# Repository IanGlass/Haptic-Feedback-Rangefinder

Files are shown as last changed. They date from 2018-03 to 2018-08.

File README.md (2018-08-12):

# Haptic-Feedback-Rangefinder

The purpose of this project was to design a hand held rangefinder which uses vibration intensity (haptic feedback) to indicate distance. The sensing range can be cycled between 100, 200 and 400 cm using the push button, where the intensity of vibration indicates the distance from the maximum distance. A switch is also present to switch the device on and off. The device also has charge indication to let the user know it is charging, by way of a couple of vibrations as feedback. The device will not operate when in charge mode. This project uses the HC-SR04 ultrasonic sensor and the EFM32TG microcontroller produced by SiliconLabs.

# Circuit

The Li-ion battery is voltage regulated to a nominal 3.5 V, providing power to the microcontroller. Battery charge is controlled with the MCP73831, which is powered through a 5 V USB source. MOSFETs are not required for normal operation but allows the micro to power up and indicate 'charging' with a few short vibration bursts from the motor (Charge tag leading to PA0 on the micro). The device has a 50 mA average measured current usage. 

<p align="center">
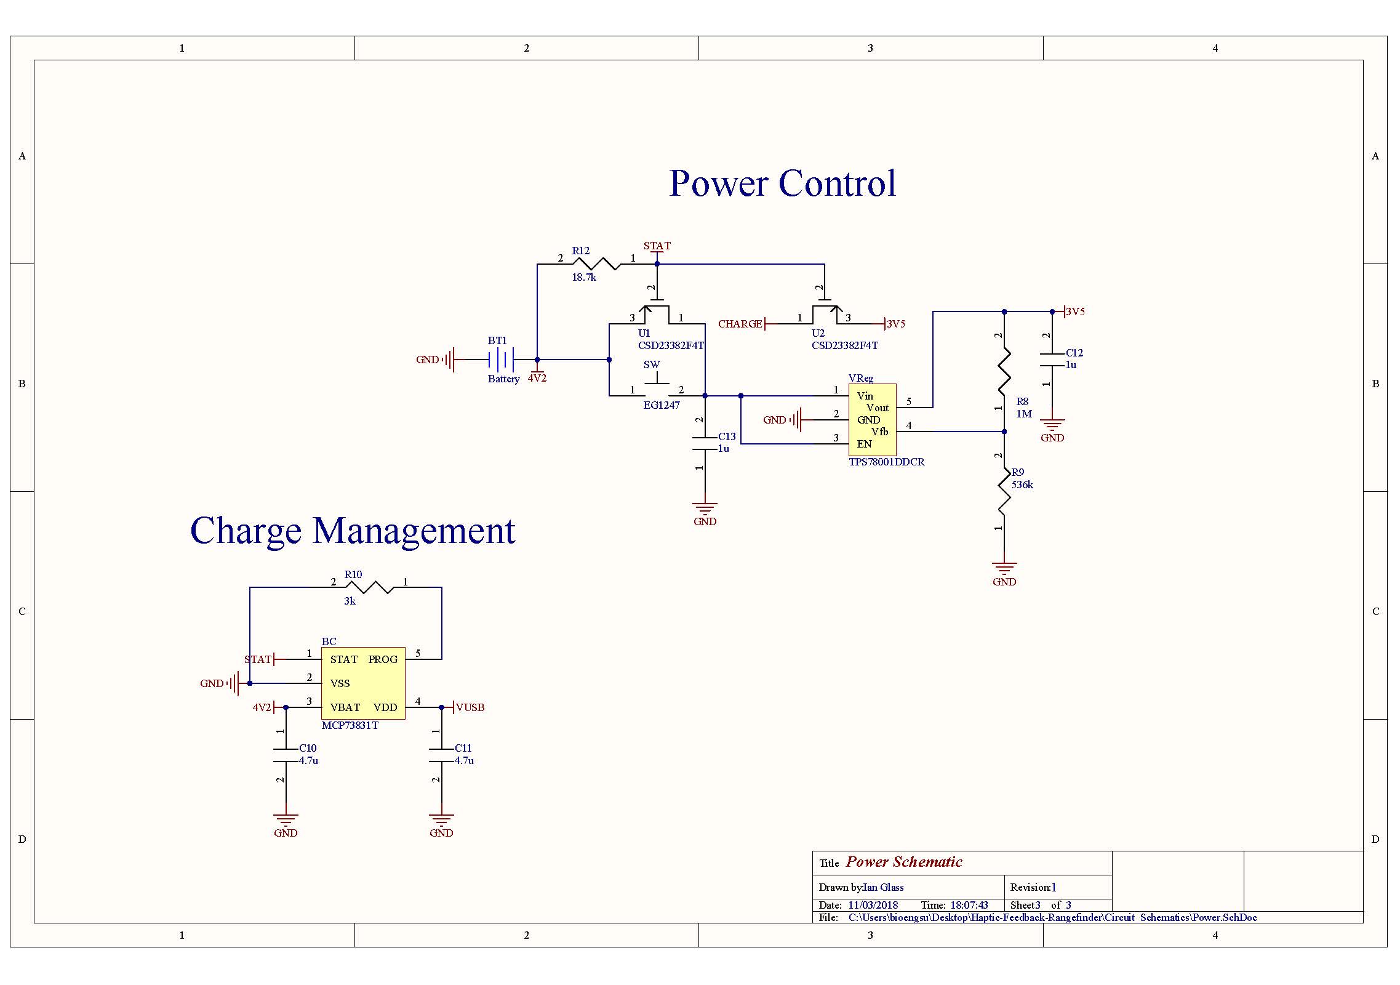
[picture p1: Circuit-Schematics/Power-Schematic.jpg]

</p>

The MCP1640 boost converter is required and adjusted to boost the 3.5 V regulated power source to 5 V, the operating voltage of the HC-SR04 sensor.

<p align="center">
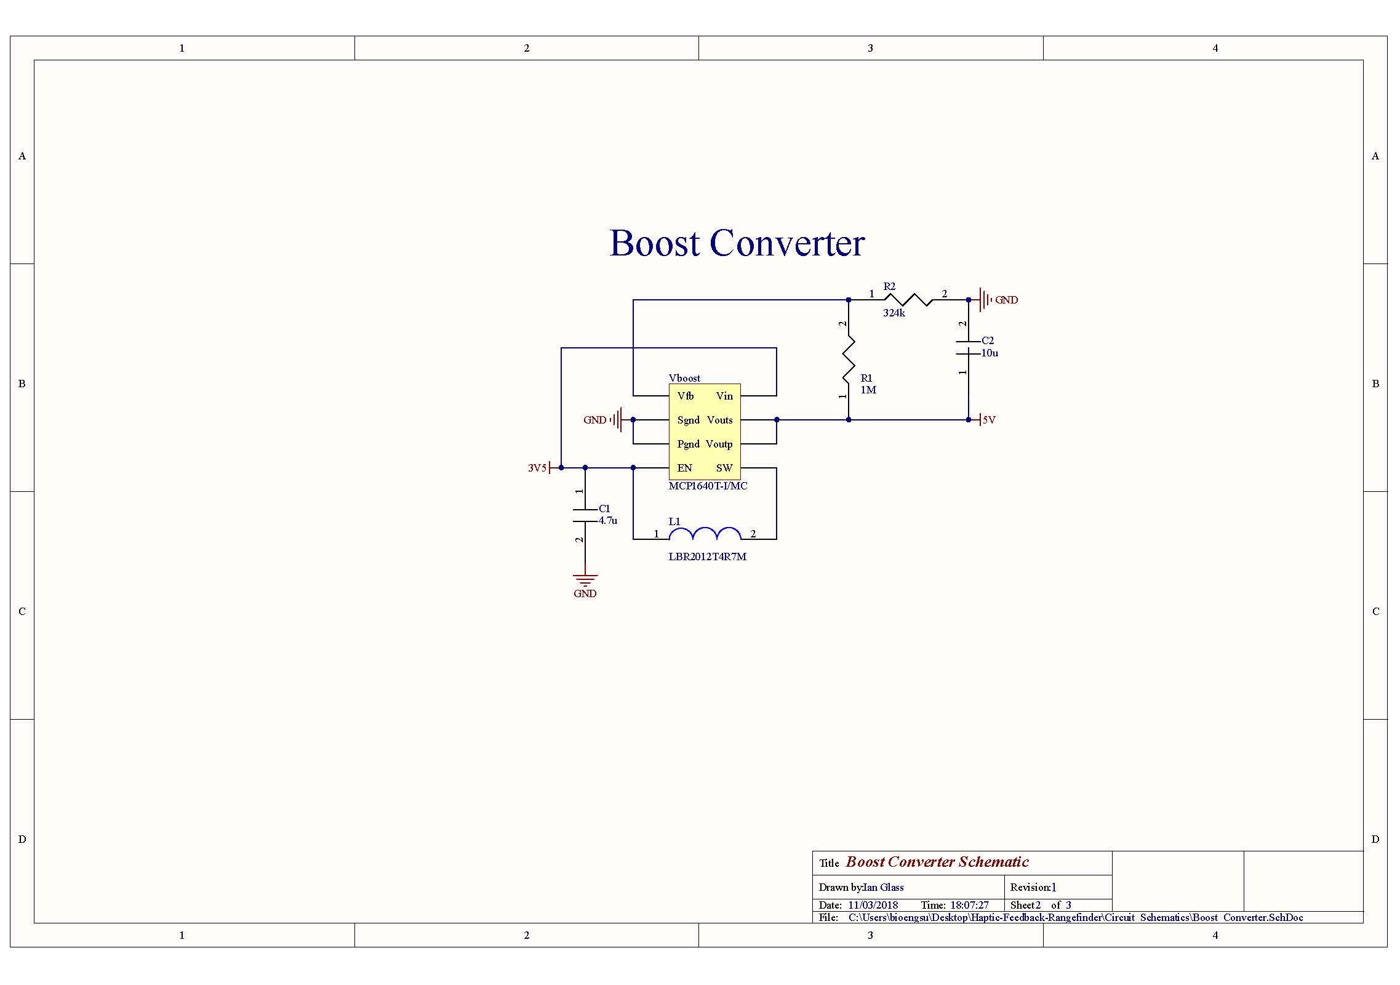
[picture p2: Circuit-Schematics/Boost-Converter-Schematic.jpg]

</p>

The EFM32TG is programmed and debugged through the Serial Wire Debug header and can be powered through USB. The HC-SR04 sensor is connected to the EFM32TG through two GPIO ports (Echo and Trig). These two pins are used to trigger range acquisition and to echo the result. An LMV321 operational amplifier is used in non-inverting mode to boost the microcontroller drive current to the motor and to smooth out the PWM signal to an analogue voltage. A program header is included to interface to a J-Link LITE CortexM via SWD for flashing and debugging using Simplicity Studio.

<p align="center">
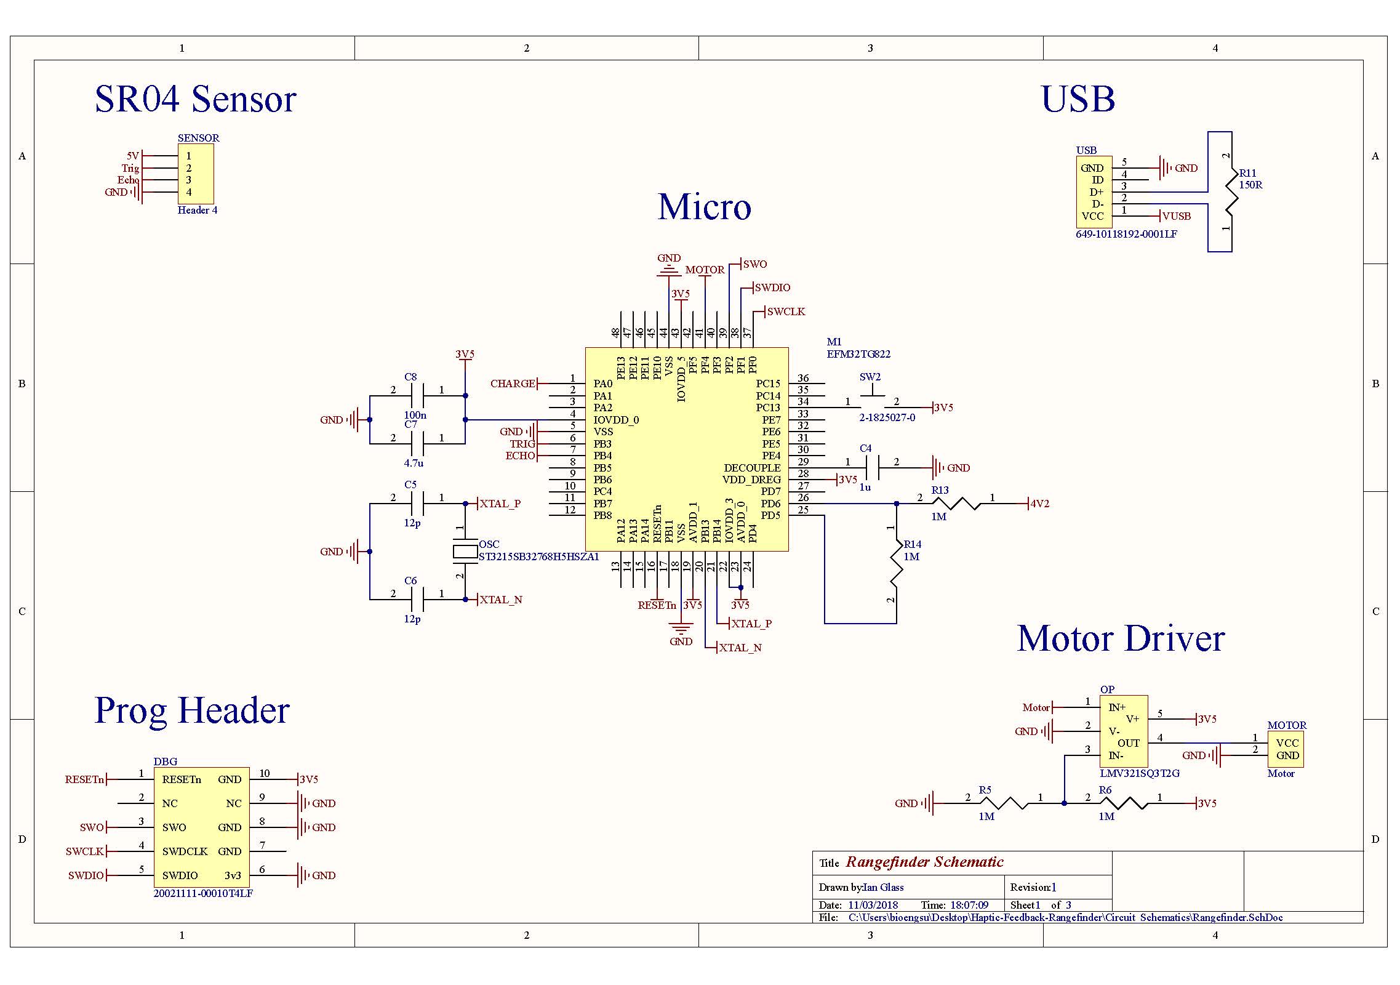
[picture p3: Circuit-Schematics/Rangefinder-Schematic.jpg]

</p>
<p align="center">
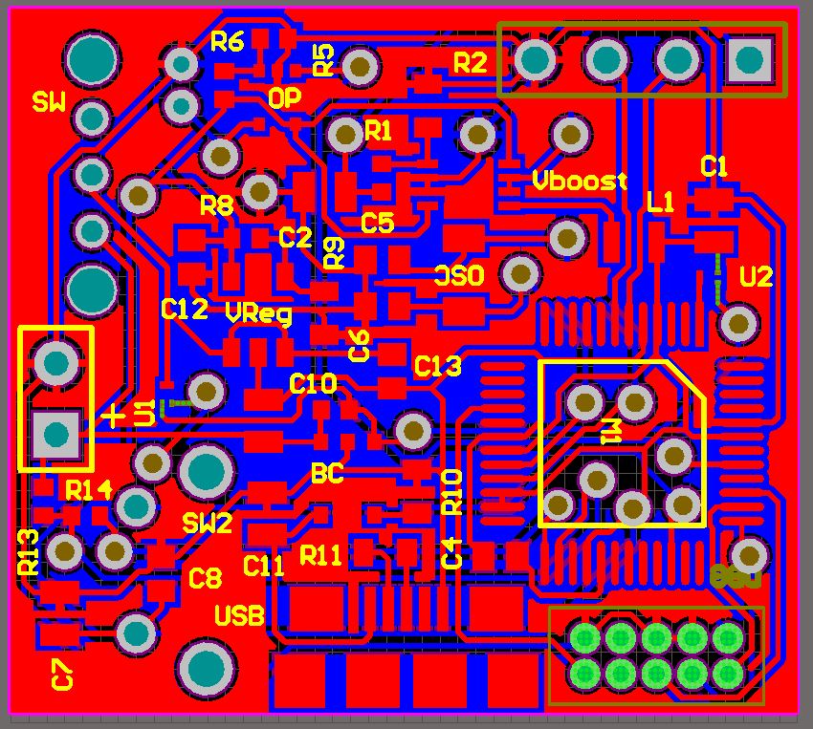
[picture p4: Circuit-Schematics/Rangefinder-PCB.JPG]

</p>

# Code

The code runs on event driven foreground tasks only (IRQs) and does not use any background operation. The HC-SR04 has a sensing range of 2 cm to 400 cm and operates by measuring the time of flight of eight 40 kHz sound pulses sent when triggered with a 10 us high digital input signal. Distance is calculated by measuring the high time of an output pin connected to the micro, where the range = high time * 340 (m/s) / 2.
The following code excerpt runs on the *TIMER1* peripheral to send 10 us long GPIO high signals to the HC-SR04 TRIG pin at a rate of 25 Hz, giving a sample rate of 25 Hz before averaging.
```c
/*-----------------------------------------------------------*/
/**
  * @brief Sends trigger signal to HC-SR04 at 25 Hz
  * @param  None
  * @retval None
  */
void TIMER1_IRQHandler(void) {
	/* Reset overflow flag */
	TIMER_IntClear(TIMER1, TIMER_IF_OF);
	/* Turn trigger on if off before */
	if (GPIO_PinInGet(TRIG_PORT, TRIG_PIN) == 0) {
		GPIO_PinOutSet(TRIG_PORT, TRIG_PIN);
		/* Set overflow value to trigger timer in 10 us */
		TIMER_TopSet(TIMER1, CMU_ClockFreqGet(cmuClock_HFPER)/TRIGGER_HIGH_FREQ/16);
	}
	/* Switch back to regular trigger timing */
	else {
		GPIO_PinOutClear(TRIG_PORT, TRIG_PIN);
		/* Set overflow value to call timer at 25Hz */ 
		TIMER_TopSet(TIMER1, CMU_ClockFreqGet(cmuClock_HFPER)/TRIGGER_CALL_FREQ);
	}
}
```

The *SYSTICK* IRQ increments a counter variable every 10 us, which is used for th Tof measurement. This IRQ is triggered on both edges of the *ECHO* pin. If the pin is high, the function resets the *SYSTICK* counter, and when the pin is low, the counter is indicative of ToF. This IRQ performs 5 point averaging when 5 samples are acquired, reducing the overall sampling rate of the system to 5 Hz. This IRQ also detects a charge event, when the device is plugged into USB, which triggers another IRQ to indicate charging through haptic feedback and stops operation. The PWM signal is calculated as a percentage of the current average distance and the maximum detection range set by pushing the button.
```c
/*-----------------------------------------------------------*/
/**
  * @brief Captures 'time-of-flight' and detect if charging
  * to triffer charge detection
  * @param  None
  * @retval None
  */
void GPIO_EVEN_IRQHandler(void) {
	/* If echo high start timer */
	if (GPIO_PinInGet(ECHO_PORT, ECHO_PIN) == 1) {
		Time = 0;
	}
	/* If echo low stop timer */
	else if (GPIO_PinInGet(ECHO_PORT, ECHO_PIN) == 0) {
		//Distance in cm, definitely works!
		Distance[SampleCount] = Time*340/(1000000/SYS_FREQ)/2;
		SampleCount++;
	}
	if ((SampleCount >= 4) && (!Charging)) {
		SampleCount = 0;
		//Needs to scale 30-90% as motor has min starting voltage. PWM and distance inversely proportional
		PWM = 100 - ((Distance[0] + Distance[1] + Distance[2] + Distance[3])/4*100/Range);
		//Can go -Ve if Distance>range
		if (PWM < 0) {
			PWM = 0;
		}
	}

	/* Detect of charging from USB */
	if (GPIO_PinInGet(CHARGE_PORT, CHARGE_PIN) == 1) {
		Charging = 1;
	}
	if (GPIO_PinInGet(CHARGE_PORT, CHARGE_PIN) == 0) {
		Charging = 0;
		/* Reset indicated charge when unplugged */
		Charge_Indicated = 0;
	}
	GPIO_IntClear(1 << ECHO_PIN);
	GPIO_IntClear(1 << CHARGE_PIN);
}
```

This IRQ has three functions: drive the PWM output to the op amp and motor, perform counting to debounce the button used for range switching and perform haptic feedback on a charge event. Motor PWM is achieved by using a counter which is incremented on each call of the IRQ. Button debounce is achieved in a similar manner. 
```c
/*-----------------------------------------------------------*/
/**
  * @brief PWM output to drive motor, performs button debounce
  * performs charge indication by haptic feedback
  * @param  None
  * @retval None
  */
void TIMER0_IRQHandler(void) {
	TIMER_IntClear(TIMER0, TIMER_IF_OF);
	PWMTime++;
	/* Turn PWM off if timer < PWM variable */
	if (PWMTime >= PWM) {
		GPIO_PinOutClear(PWM_PORT, PWM_PIN);
	}
	else {
		GPIO_PinOutSet(PWM_PORT, PWM_PIN);
	}
	if (PWMTime >= 100) {
		PWMTime = 0;
	}

	Debounce++;
	if (Debounce > 400) {
		Button_Enable = 1;
	}
	if (!Sensor_On) {
		/* Set motor on time to 1/2 total time */
		PWM = 50;
		/* Change pwm timer freq to 5Hz */
		TIMER_TopSet(TIMER0, CMU_ClockFreqGet(cmuClock_HFPER)/RANGE_FREQ);
		Indicator_Counter++;
		/* If finished indicating range, turn everything back on */
		if (Indicator_Counter/100 >= Indicator_Counter_Max) {
			/* Reset PWM to normal frequency */
			TIMER_TopSet(TIMER0, CMU_ClockFreqGet(cmuClock_HFPER)/PWM_FREQ);
			/* Turn trigger timer back on */
			TIMER_IntEnable(TIMER1, TIMER_IF_OF);
			Sensor_On = 1;
		}
	}
	if ((Charging) && (!Charge_Indicated)) {
		PWM = 50;
		/* Change pwm timer freq to 5Hz */
		TIMER_TopSet(TIMER0, CMU_ClockFreqGet(cmuClock_HFPER)/RANGE_FREQ);
		Charge_Counter++;
		if (Charge_Counter >= 100) {
			/* Reset PWM to normal frequency */
			TIMER_TopSet(TIMER0, CMU_ClockFreqGet(cmuClock_HFPER)/PWM_FREQ);
			Charge_Counter = 0;
			Charge_Indicated = 1;
			PWM = 0;
		}
	}
}
```

This IRQ exclusively checks for a button push event and switches the range between 100, 200 and 400 cm. This range is used in previous IRQs to scale the vibration intensity with currently sensed distance.
```c
/*-----------------------------------------------------------*/
/**
  * @brief Switches between 100, 200 and 400 cm when button pressed
  * @param  None
  * @retval None
  */
void GPIO_ODD_IRQHandler(void) {
	/* Button check for button pressed and perform debounce */
	if ((GPIO_PinInGet(BUTTON_PORT, BUTTON_PIN) == 1) && Button_Enable && !Prev_State && !Charging){
		Debounce = 0;
		Button_Enable = 0;
		/* Switch Range */
		if (Range == 100) {
			Range = 200;
			Indicator_Counter_Max = 2;
		}
		else if (Range == 200) {
			Range = 400;
			Indicator_Counter_Max = 4;
		}
		else {
			Range = 100;
			Indicator_Counter_Max = 1;
		}
		/* Turn off trigger timer */
		TIMER_IntDisable(TIMER1, TIMER_IF_OF);
		Indicator_Counter = 0;
		Sensor_On = 0;
		Prev_State = 1;
	}
	/* Make sure button has been released before allowing another push */
	else if ((GPIO_PinInGet(BUTTON_PORT, BUTTON_PIN) == 0) && Prev_State) {
		Prev_State = 0;
	}
	GPIO_IntClear(1 << BUTTON_PIN);
}
```

# Case

The device consists of a (top to bottom) a top case piece, the HC-SR04 sensor, the populated PCB, a Li battery, the motor and the bottom piece. The case is 3D printed from PLA and can be super glued together.

<p align="center">
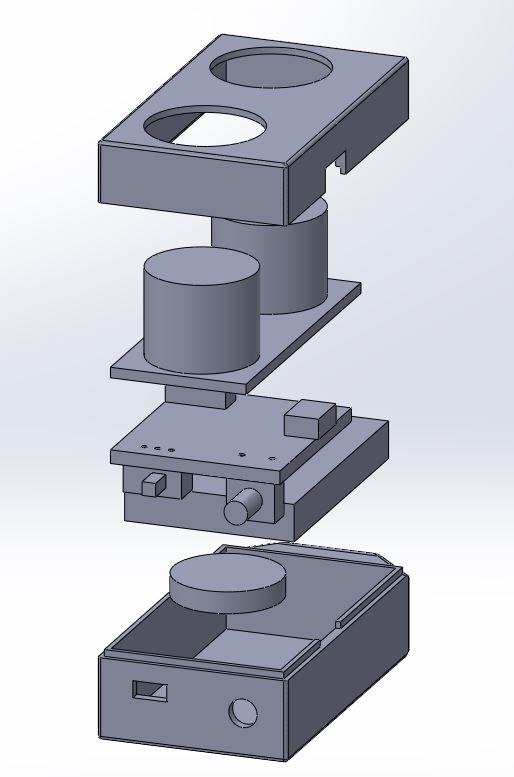
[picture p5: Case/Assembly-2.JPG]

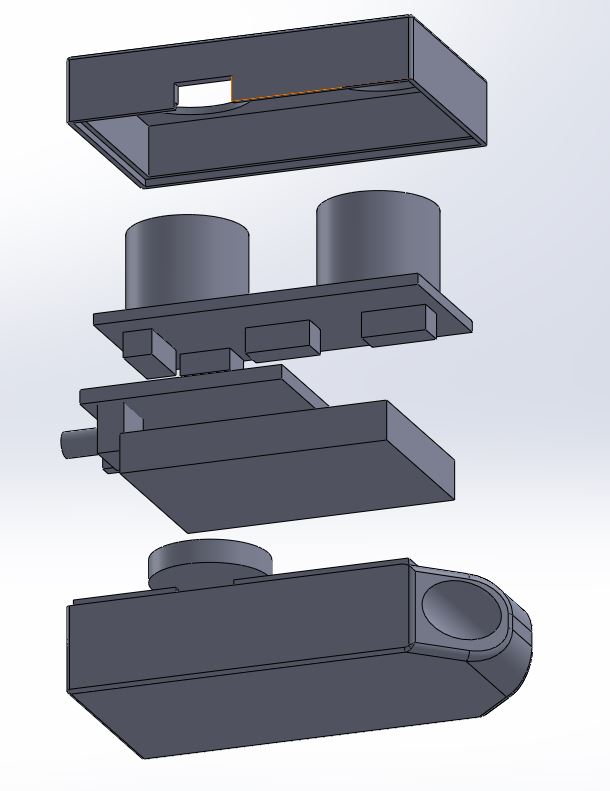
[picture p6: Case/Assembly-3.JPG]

</p>
<p align="center">
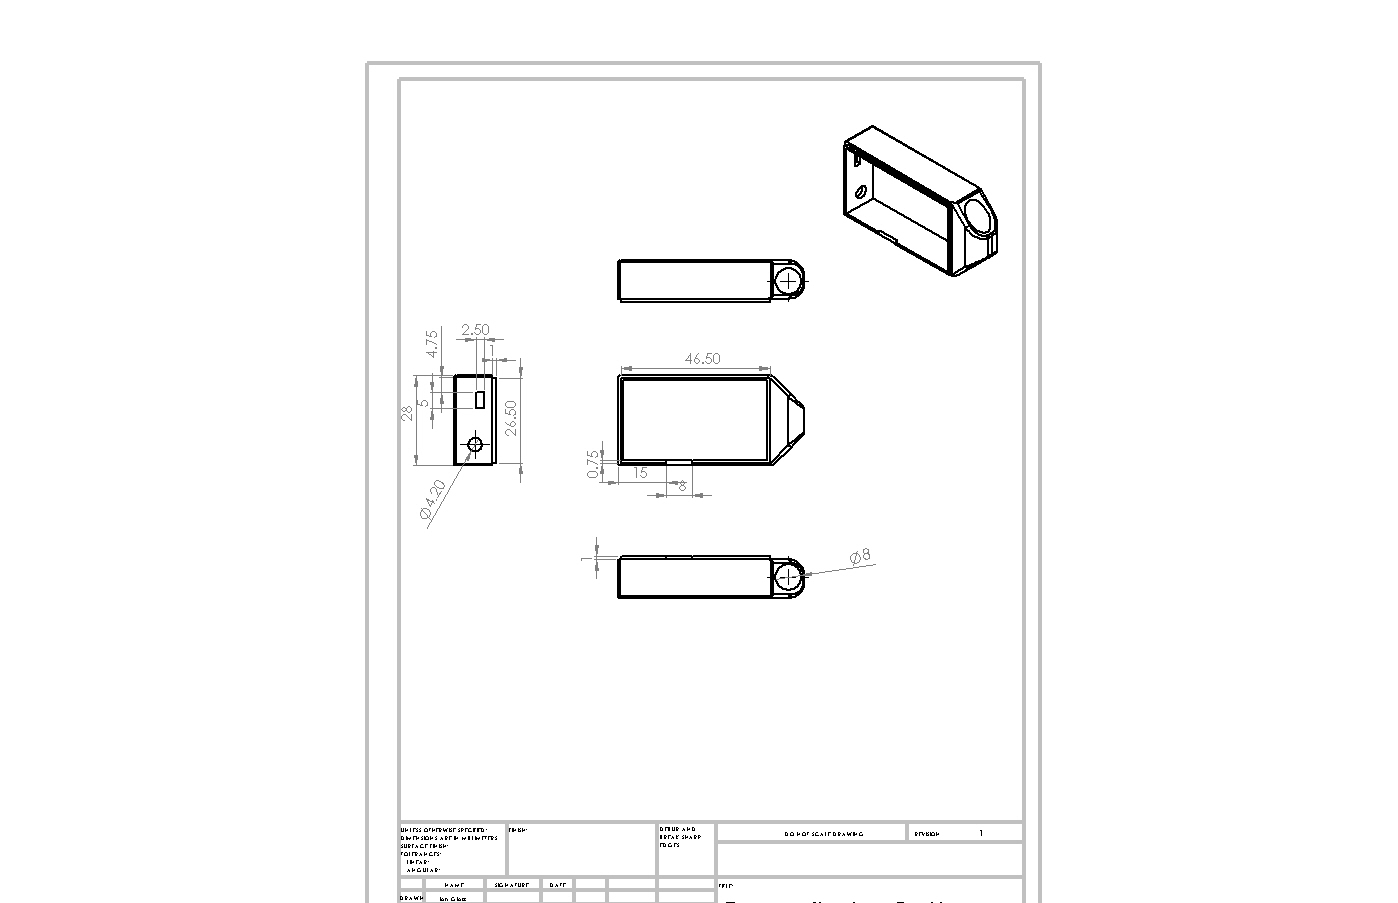
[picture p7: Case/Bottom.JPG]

</p>
<p align="center">
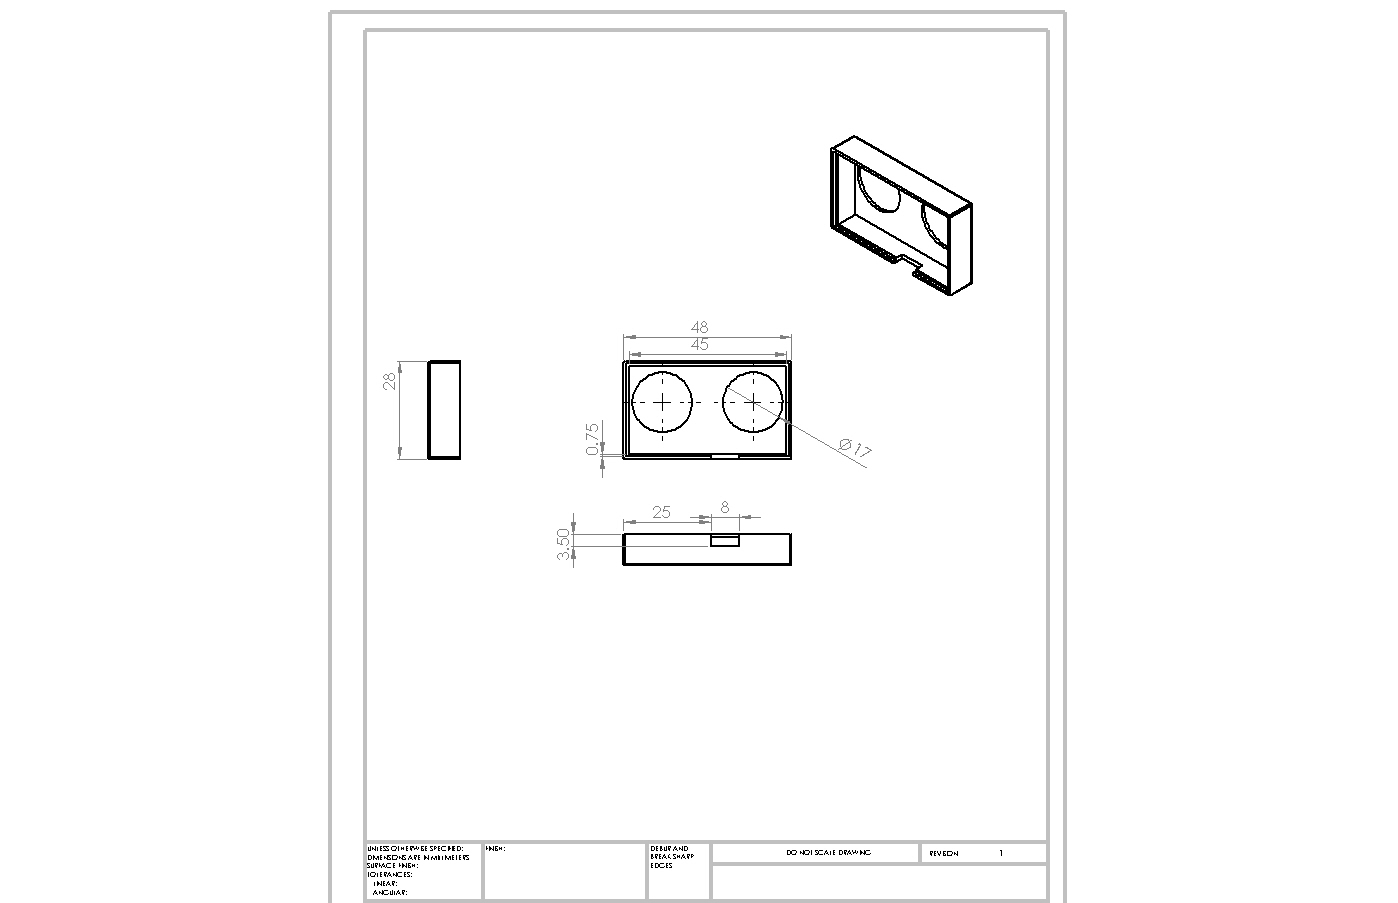
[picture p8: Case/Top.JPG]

</p>

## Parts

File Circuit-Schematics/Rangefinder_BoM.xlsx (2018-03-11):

Part type | Mouser Part number | Manufacturer Parts Number | Supplier | Mounting Side | Tolerance (%) | # per board | unit price ($)
MCU | 904-EFM32TG822F32 | EFM32TG822F32-QFP48 | Mouser | Top |  | 1 | 3.51
Boost Converter | 579-MCP1640TI/MC | MCP1640T-I/MC | Mouser | Top |  | 1 | 1.1
V reg | 595-TPS78001DDCR | TPS78001DDCR | Mouser | Top |  | 1 | 1.7
Op Amp | 863-LMV321SQ3T2G | LMV321SQ3T2G | Mouser | Top |  | 1 | 0.835
Charger IC | 579-MCP73832T-2ACIOT | MCP73832T-2ACI/OT | Mouser | Top |  | 1 | 1
Osc | 581-ST3215SB3H5HSZA1 | ST3215SB32768H5HSZA1 | Mouser | Top |  | 1 | 1.35
Inductor | 963-LBR2012T4R7M | LBR2012T4R7M | Mouser | Top | 20 | 1 | 0.167
PMOSFET | 595-CSD23382F4T | CSD23382F4T | Mouser | Top |  | 2 | 0.752
Cap 10uf | 77-VJ0805G106KXQTBC | VJ0805G106KXQTW1BC | Mouser | Top | 10 | 1 | 0.167
Cap 4.7uf | 77-VJ0805G475KXYTBC | VJ0805G475KXYTW1BC | Mouser | Top | 10 | 4 | 0.167
Cap 12pf | 581-04025A120J | 04025A120JAT2A | Mouser | Top | 5 | 2 | 0.167
Cap 1uf | 710-885012106017 | 885012106017 | Mouser | Top | 20 | 3 | 0.134
Cap 100nf | 77-VJ0402V104ZXJCBC | VJ0402V104ZXJCW1BC | Mouser | Top | 20 | 1 | 0.117
Res 1M | 71-CRCW0402-1.0M-E3 | CRCW04021M00FKED | Mouser | Top | 1 | 6 | 0.167
Res 324k | 754-RR0816P-3243D50D | RR0816P-3243-D-50D | Mouser | Top | 0.5 | 1 | 0.167
Res 18.7k | 754-RR0510P-1872D | RR0510P-1872-D | Mouser | Top |  | 1 | 0.117
Res 3k | 754-RR0816P-302D | RR0816P-302-D | Mouser | Top | 0.5 | 1 | 0.167
Res 536k | 603-RT0603BRD07536KL | RT0603BRD07536KL | Mouser | Top | 1 | 1 | 0.551
Res 150R | 594-MCT06030C1500FP5 | MCT06030C1500FP500 | Mouser | Top | 1 | 1 | 0.167
Header debug | 649-221111-00010T4LF | 20021111-00010T4LF | Mouser | Top |  | 1 | 1.07
Switch | 612-EG1247 | EG1247 | Mouser | Bottom |  | 1 | 1.09
Button | 506-FSMRA4JH | FSMRA4JH04 | Mouser | Bottom |  | 1 | 0.384
USB | 649-10118193-0001LF | 10118193-0001LF | Mouser | Top |  | 1 | 0.685
Battery | http://www.alibaba.com/product-detail/Shenzhen-China-Litium-ion-Battery-3_1354542923.html |  | Alibaba | Bottom |  | 1 | 2.4
Motor | http://www.alibaba.com/product-detail/high-qunatity-cell-phone-vibration-motor_1698966227.html |  | Alibaba | Bottom |  | 1 | 0.6
Sensor | SR04 |  | Alibaba | Top |  | 1 | 0.1
 |  |  |  |  |  | 38

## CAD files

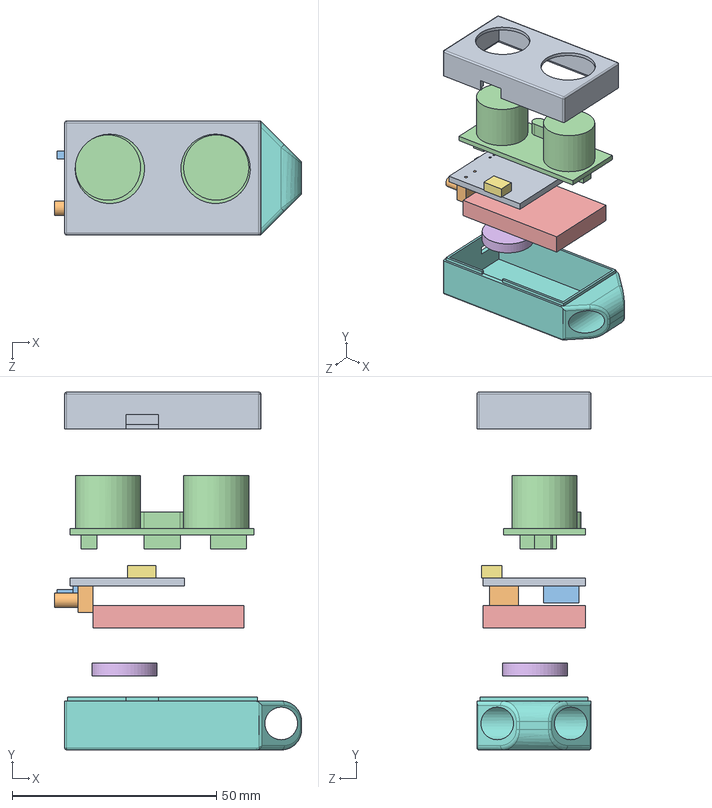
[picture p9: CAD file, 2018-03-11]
Case/Assem1.SLDASM
60.5 x 87.6 x 28.0 mm
PCB
Button
Switch
Sensor
Battery
Motor
USB
Bottom
Top

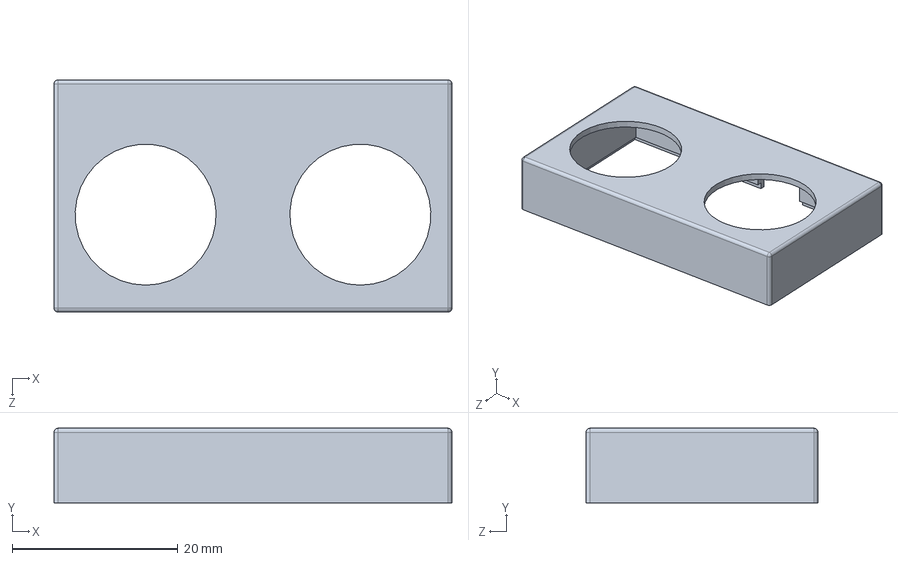
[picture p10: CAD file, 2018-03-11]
Case/Top.SLDPRT
48.0 x 9.00 x 28.0 mm

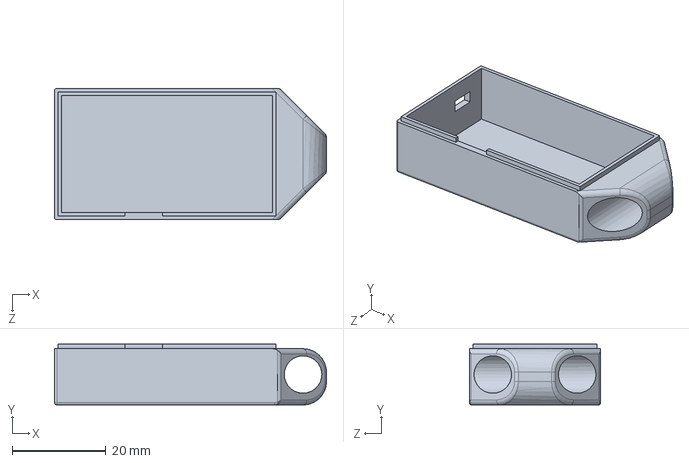
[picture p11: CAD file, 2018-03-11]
Case/Bottom.SLDPRT
58.0 x 13.0 x 28.0 mm

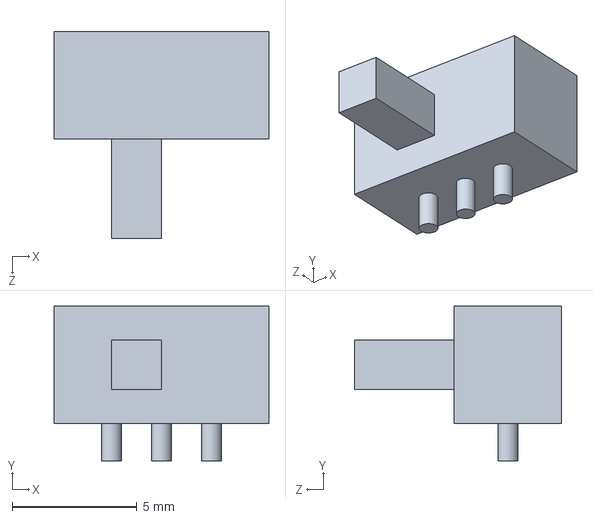
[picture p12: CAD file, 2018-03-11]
Case/Switch.SLDPRT
8.60 x 6.20 x 8.30 mm

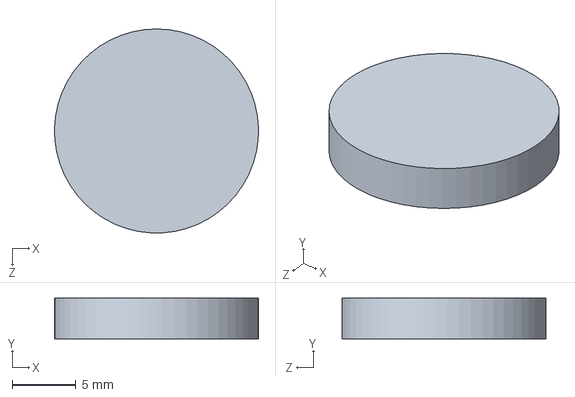
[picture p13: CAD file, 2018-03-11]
Case/Motor.SLDPRT
16.0 x 3.20 x 16.0 mm

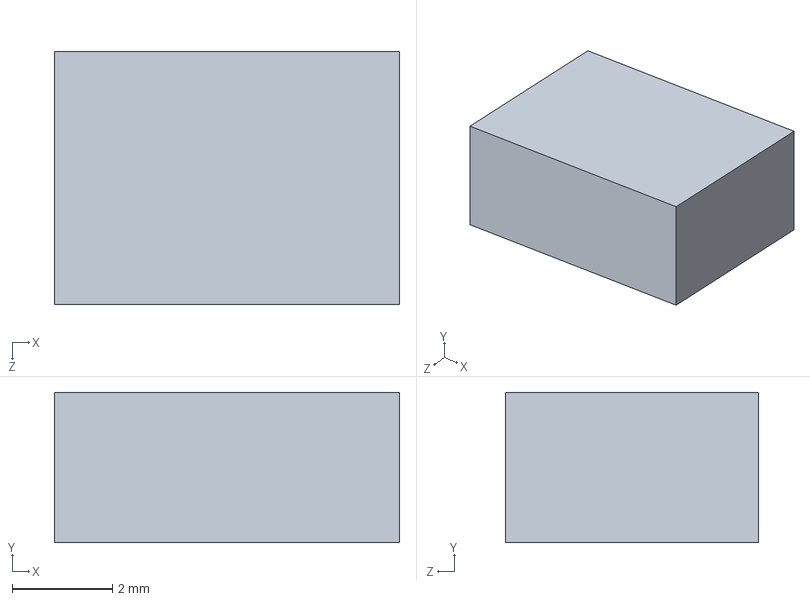
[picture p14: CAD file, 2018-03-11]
Case/USB.SLDPRT
6.90 x 3.00 x 5.05 mm

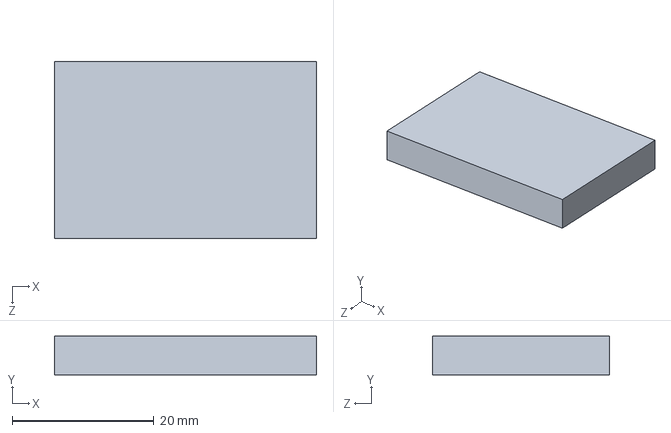
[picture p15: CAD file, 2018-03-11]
Case/Battery.SLDPRT
37.0 x 5.50 x 25.0 mm

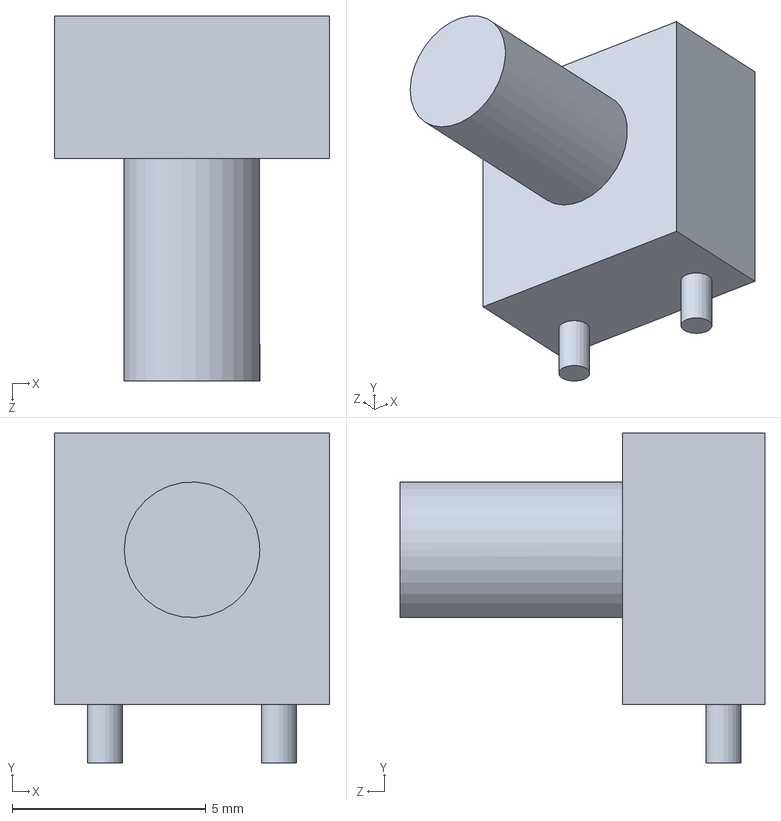
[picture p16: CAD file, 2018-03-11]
Case/Button.SLDPRT
7.11 x 8.51 x 9.42 mm

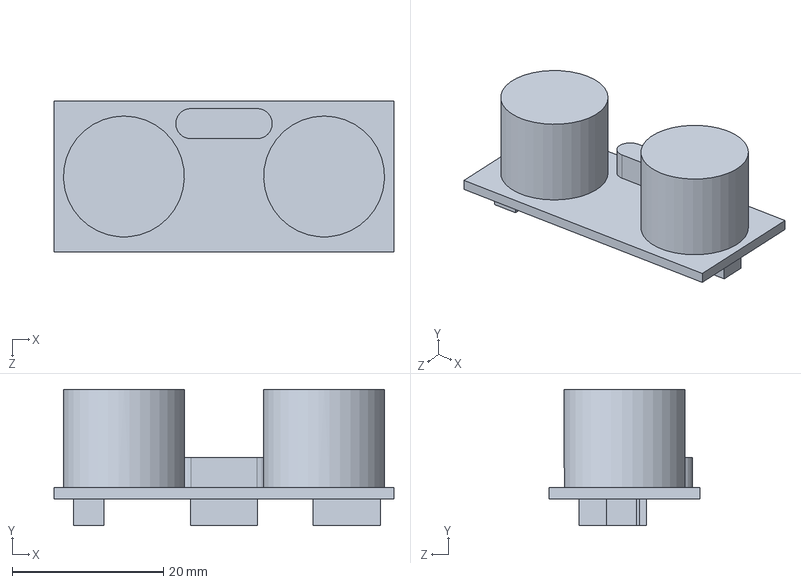
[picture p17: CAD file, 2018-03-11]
Case/Sensor.SLDPRT
45.0 x 18.0 x 20.0 mm

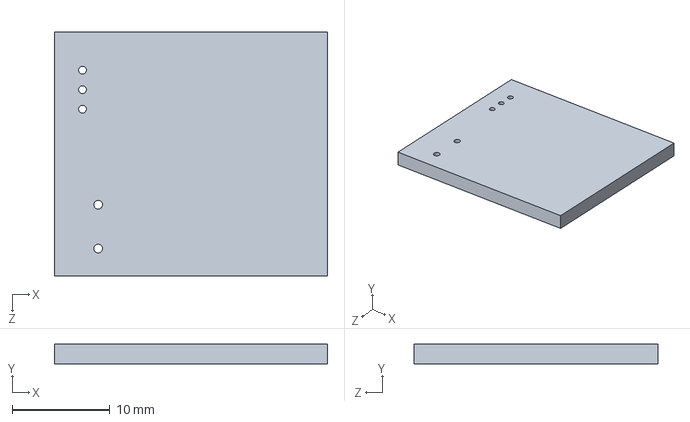
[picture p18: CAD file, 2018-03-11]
Case/PCB.SLDPRT
28.0 x 2.00 x 25.0 mm

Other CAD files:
Case/Bottom.SLDDRW
Case/Bottom.STL
Case/Top.SLDDRW
Case/Top.STL

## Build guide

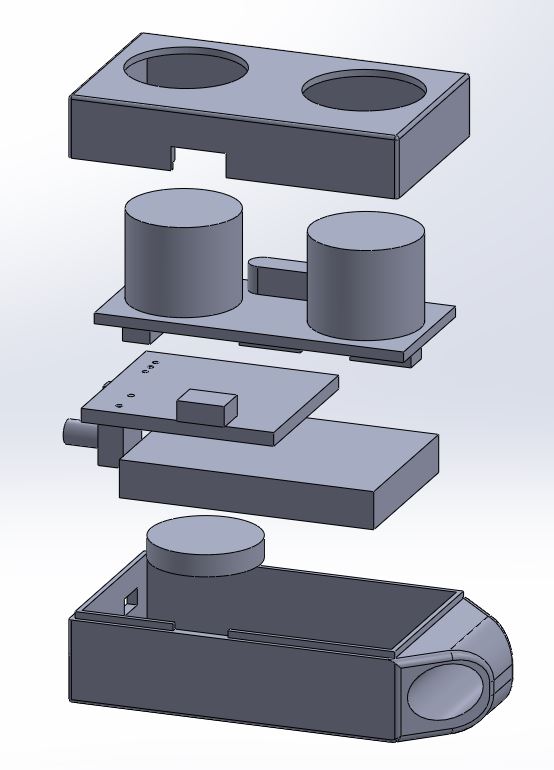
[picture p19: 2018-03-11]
Case/Assembly-1.JPG

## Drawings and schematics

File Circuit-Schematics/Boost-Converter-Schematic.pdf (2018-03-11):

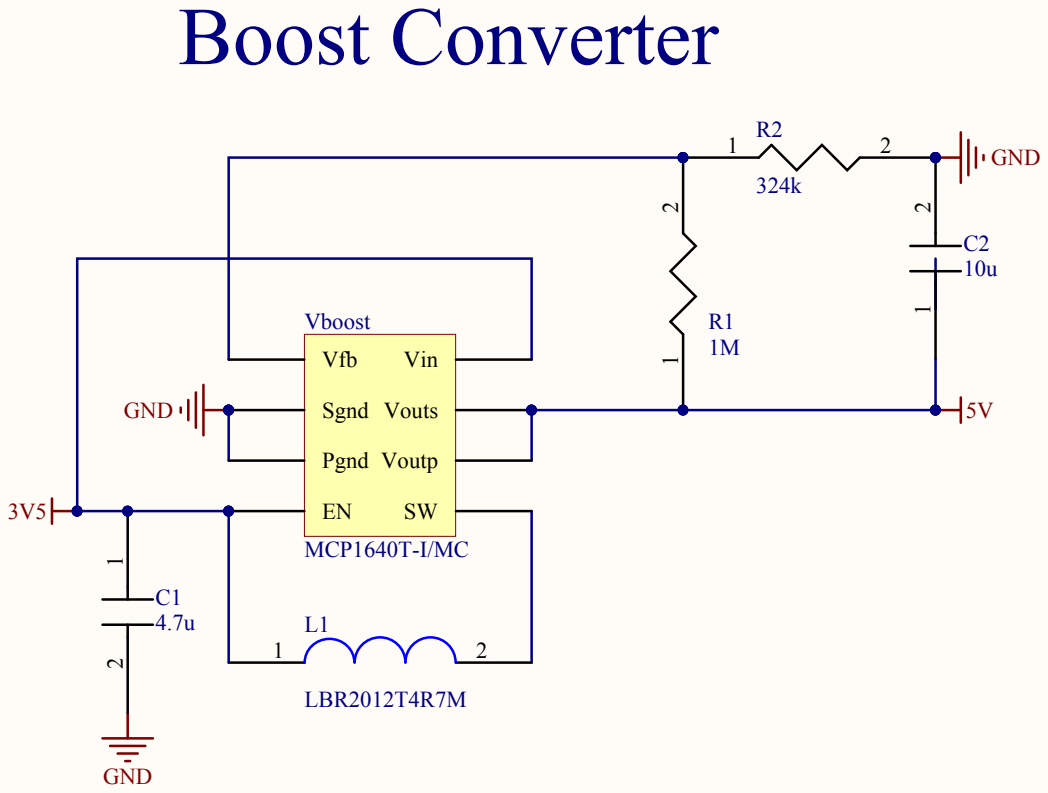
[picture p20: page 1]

Vfb Vin Sgnd Vouts Pgnd Voutp

Boost Converter Schematic Title

Drawn by: Ian Glass | Revision: 1

Date: 11/03/2018 Time: 18:07:27 | Sheet 2 of 3

C:\Users\bioengsu\Desktop\Haptic-Feedback-Rangefinder\Circuit_Schematics\Boost_Converter.SchDoc

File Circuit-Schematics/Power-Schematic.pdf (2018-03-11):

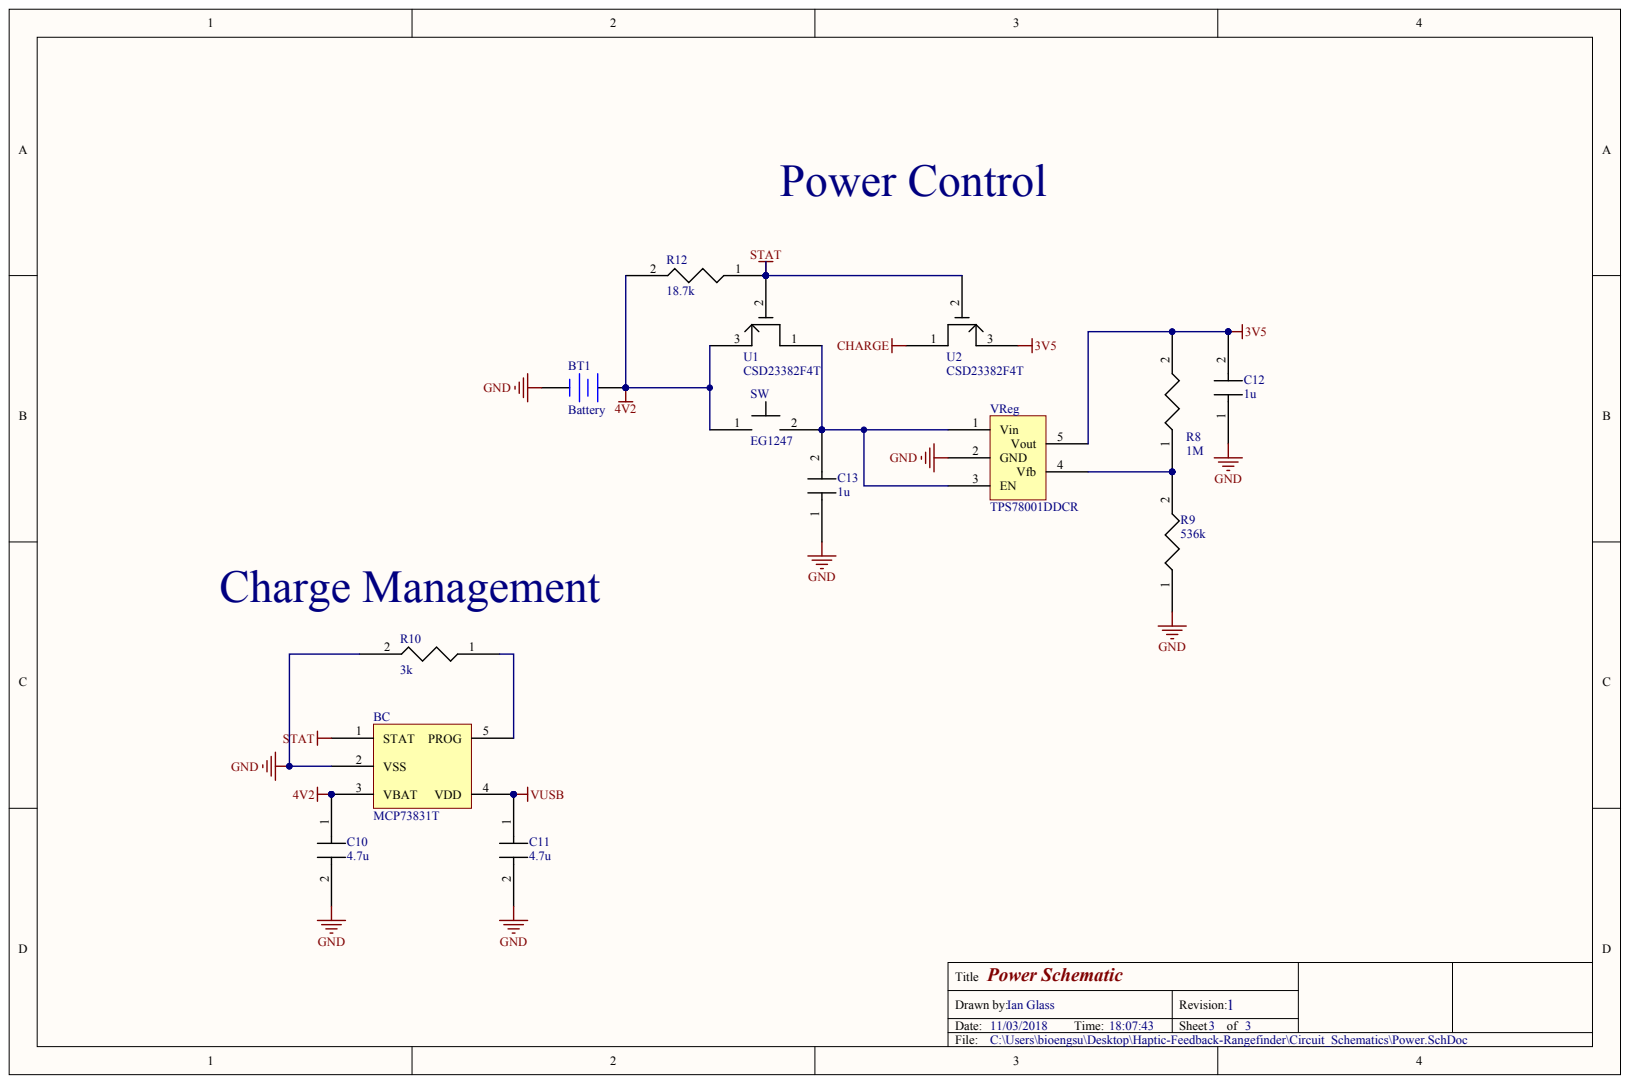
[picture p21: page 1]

Power Schematic Title

Drawn by: Ian Glass | Revision: 1

Date: 11/03/2018 Time: 18:07:43 | Sheet 3 of 3

C:\Users\bioengsu\Desktop\Haptic-Feedback-Rangefinder\Circuit_Schematics\Power.SchDoc

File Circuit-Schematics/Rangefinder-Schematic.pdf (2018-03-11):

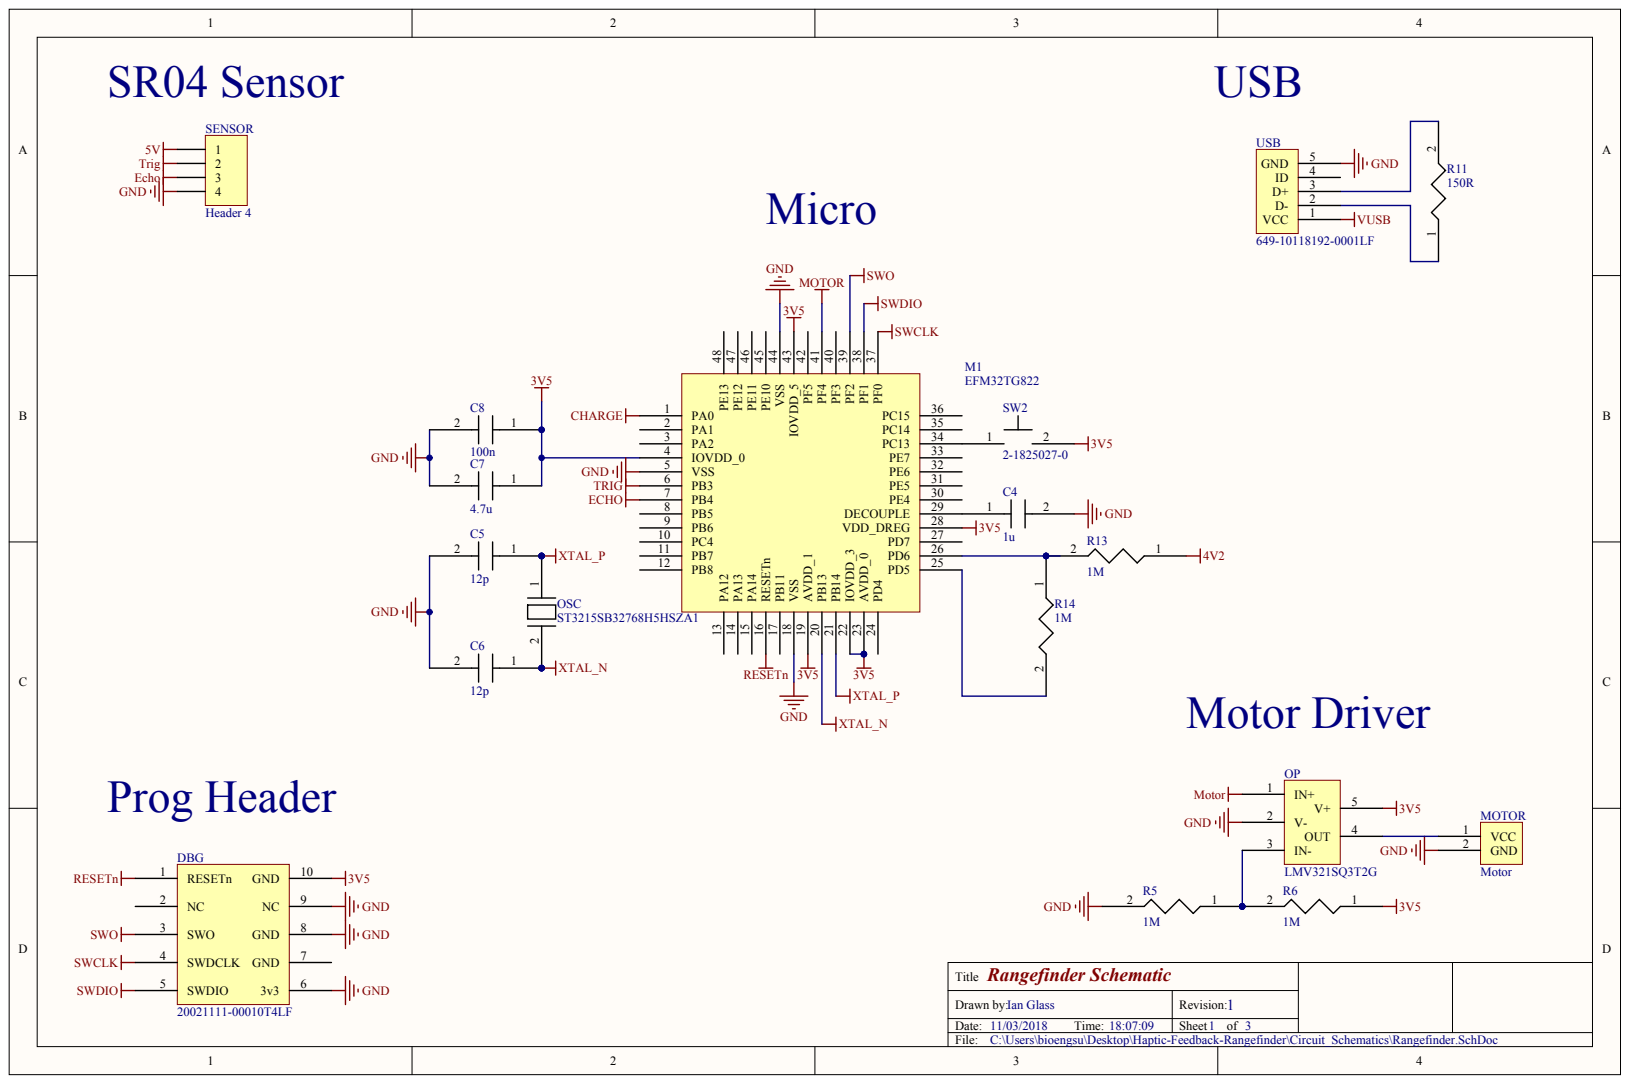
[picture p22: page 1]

Rangefinder Schematic Title

Drawn by: Ian Glass | Revision: 1

Date: 11/03/2018 Time: 18:07:09 | Sheet 1 of 3

C:\Users\bioengsu\Desktop\Haptic-Feedback-Rangefinder\Circuit_Schematics\Rangefinder.SchDoc

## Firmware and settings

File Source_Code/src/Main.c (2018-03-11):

/**************************************************************************//**
 * @file
 * @brief Empty Project
 * @author Energy Micro AS
 * @version 3.20.2
 ******************************************************************************
 * @section License
 * <b>(C) Copyright 2014 Silicon Labs, http://www.silabs.com</b>
 *******************************************************************************
 *
 * This file is licensed under the Silicon Labs Software License Agreement. See 
 * "http://developer.silabs.com/legal/version/v11/Silicon_Labs_Software_License_Agreement.txt"  
 * for details. Before using this software for any purpose, you must agree to the 
 * terms of that agreement.
 *
 ******************************************************************************/

#ifndef TRIG_PIN
#define TRIG_PIN     3
#endif
#ifndef TRIG_PORT
#define TRIG_PORT    gpioPortB
#endif
#ifndef ECHO_PIN
#define ECHO_PIN     4
#endif
#ifndef ECHO_PORT
#define ECHO_PORT    gpioPortB
#endif
#ifndef PWM_PIN
#define PWM_PIN     4
#endif
#ifndef PWM_PORT
#define PWM_PORT    gpioPortF
#endif
#ifndef BUTTON_PIN
#define BUTTON_PIN     13
#endif
#ifndef BUTTON_PORT
#define BUTTON_PORT    gpioPortC
#endif
#ifndef CHARGE_PIN
#define CHARGE_PIN     0
#endif
#ifndef CHARGE_PORT
#define CHARGE_PORT    gpioPortA
#endif

#include <stdint.h>
#include <stdbool.h>
#include <stdio.h>
#include "em_device.h"
#include "em_chip.h"
#include "em_cmu.h"
#include "em_emu.h"
#include "em_gpio.h"
#include "em_int.h"
#include "em_timer.h"
#include "em_prs.h"
#include "em_msc.h"
//
//
//
//

//Optimal without signal cross-over
#define TRIGGER_CALL_FREQ 25
//Set to 40us high time
#define TRIGGER_HIGH_FREQ 25000
//PWM CALL frequency (100 times PWM frequency). Should be no greater than time to acquire 5 samples
#define PWM_FREQ 100000 //25000
//Systick call frequency
#define SYS_FREQ 10000
//Frequency for range indicator (set to 2 Hz atm)
#define RANGE_FREQ 200

volatile uint32_t Time;
volatile uint32_t PWMTime;
volatile uint32_t Debounce = 0;
volatile uint32_t Button_Enable = 1;
volatile uint32_t Sensor_On = 1;
volatile uint32_t Charging = 0;
int Distance[5];
int SampleCount = 0;
int PWM = 0;
//Range in cm, init
uint32_t Range = 100;
int Prev_State = 0;
int Indicator_Counter = 0;
int Indicator_Counter_Max = 0;
int Charge_Counter = 0;
int Charge_Indicated = 0;

uint32_t clock;

/**************************************************************************//**
 * @brief SysTick_Handler
 * Interrupt Service Routine for system tick counter, 10us calls
 *****************************************************************************/
void SysTick_Handler(void)
{
    Time++;
}

//PWM output ISR and debounce and range switch vibration control
void TIMER0_IRQHandler(void) {
	TIMER_IntClear(TIMER0, TIMER_IF_OF);
	PWMTime++;
	//Turn PWM off if timer < PWM variable
	if (PWMTime >= PWM) {
		GPIO_PinOutClear(PWM_PORT, PWM_PIN);
	}
	else {
		GPIO_PinOutSet(PWM_PORT, PWM_PIN);
	}
	if (PWMTime >= 100) {
		PWMTime = 0;
	}
	Debounce++;
	if (Debounce > 400) {
		Button_Enable = 1;
	}
	if (!Sensor_On) {
		//Set motor on time to 1/2 total time
		PWM = 50;
		//Change pwm timer freq to 5Hz
		TIMER_TopSet(TIMER0, CMU_ClockFreqGet(cmuClock_HFPER)/RANGE_FREQ);
		Indicator_Counter++;
		//If finished indicating range, turn everything back on
		if (Indicator_Counter/100 >= Indicator_Counter_Max) {
			//Reset PWM to normal frequency
			TIMER_TopSet(TIMER0, CMU_ClockFreqGet(cmuClock_HFPER)/PWM_FREQ);
			//Turn trigger timer back on
			TIMER_IntEnable(TIMER1, TIMER_IF_OF);
			Sensor_On = 1;
		}
	}
	if ((Charging) && (!Charge_Indicated)) {
		PWM = 50;
		//Change pwm timer freq to 5Hz
		TIMER_TopSet(TIMER0, CMU_ClockFreqGet(cmuClock_HFPER)/RANGE_FREQ);
		Charge_Counter++;
		if (Charge_Counter >= 100) {
			//Reset PWM to normal frequency
			TIMER_TopSet(TIMER0, CMU_ClockFreqGet(cmuClock_HFPER)/PWM_FREQ);
			Charge_Counter = 0;
			Charge_Indicated = 1;
			PWM = 0;
		}
	}
}

//Trigger signal out
void TIMER1_IRQHandler(void) {
	//Reset overflow flag
	TIMER_IntClear(TIMER1, TIMER_IF_OF);
	//Turn trigger on if off before
	if (GPIO_PinInGet(TRIG_PORT, TRIG_PIN) == 0) {
		GPIO_PinOutSet(TRIG_PORT, TRIG_PIN);
		//Set overflow value to trigger timer in 10us
		TIMER_TopSet(TIMER1, CMU_ClockFreqGet(cmuClock_HFPER)/TRIGGER_HIGH_FREQ/16);
	}
	//Switch back to regular trigger timing
	else {
		GPIO_PinOutClear(TRIG_PORT, TRIG_PIN);
		//Set overflow value to call timer at 25Hz
		TIMER_TopSet(TIMER1, CMU_ClockFreqGet(cmuClock_HFPER)/TRIGGER_CALL_FREQ);
	}
}

void GPIO_EVEN_IRQHandler(void) {
	if (GPIO_PinInGet(CHARGE_PORT, CHARGE_PIN) == 1) {
		Charging = 1;
	}
	if (GPIO_PinInGet(CHARGE_PORT, CHARGE_PIN) == 0) {
		Charging = 0;
		//Reset indicated charge when unplugged
		Charge_Indicated = 0;
	}
	//If echo high start timer
	if (GPIO_PinInGet(ECHO_PORT, ECHO_PIN) == 1) {
		Time = 0;
	}
	//If echo low stop timer
	else if (GPIO_PinInGet(ECHO_PORT, ECHO_PIN) == 0) {
		//Distance in cm, definitely works!
		Distance[SampleCount] = Time*340/(1000000/SYS_FREQ)/2;
		SampleCount++;
	}
	if ((SampleCount >= 4) && (!Charging)) {
		SampleCount = 0;
		//Needs to scale 30-90% as motor has min starting voltage. PWM and distance inversely proportional
		PWM = 100 - ((Distance[0] + Distance[1] + Distance[2] + Distance[3])/4*100/Range);
		//Can go -Ve if Distance>range
		if (PWM < 0) {
			PWM = 0;
		}
	}
	GPIO_IntClear(1 << ECHO_PIN);
	GPIO_IntClear(1 << CHARGE_PIN);
}

void GPIO_ODD_IRQHandler(void) {
	//Button
	if ((GPIO_PinInGet(BUTTON_PORT, BUTTON_PIN) == 1) && Button_Enable && !Prev_State && !Charging){
		Debounce = 0;
		Button_Enable = 0;
		//Switch Range
		if (Range == 100) {
			Range = 200;
			Indicator_Counter_Max = 2;
		}
		else if (Range == 200) {
			Range = 400;
			Indicator_Counter_Max = 4;
		}
		else {
			Range = 100;
			Indicator_Counter_Max = 1;
		}
		//Turn off trigger timer
		TIMER_IntDisable(TIMER1, TIMER_IF_OF);
		Indicator_Counter = 0;
		Sensor_On = 0;
		Prev_State = 1;
	}
	//Make sure button has been released before allowing another push
	else if ((GPIO_PinInGet(BUTTON_PORT, BUTTON_PIN) == 0) && Prev_State) {
		Prev_State = 0;
	}
	GPIO_IntClear(1 << BUTTON_PIN);
}

/**************************************************************************//**
 * @brief  Main function
 *****************************************************************************/
int main(void)
{
  /* Chip errata */
  CHIP_Init();

  CMU_ClockEnable(cmuClock_GPIO, true);

  /* Setup SysTick Timer for 100 usec interrupts  */
  if (SysTick_Config(CMU_ClockFreqGet(cmuClock_CORE)/SYS_FREQ)) while (1) ;

  clock = SystemCoreClockGet();

  //
  //Initialise echo pin, both edges
  GPIO_PinModeSet(ECHO_PORT, ECHO_PIN, gpioModeInput, 0);
  GPIO_IntConfig(ECHO_PORT, ECHO_PIN, true, true, true);
  //Initialise button pin, both edges
  GPIO_PinModeSet(BUTTON_PORT, BUTTON_PIN, gpioModeInputPull, 0);
  GPIO_IntConfig(BUTTON_PORT, BUTTON_PIN, true, true, true);
  //Initialise charge pin, both edges
  GPIO_PinModeSet(CHARGE_PORT, CHARGE_PIN, gpioModeInputPull, 0);
  GPIO_IntConfig(CHARGE_PORT, CHARGE_PIN, true, true, true);
  //Load to interrupt vector controller
  NVIC_EnableIRQ(GPIO_ODD_IRQn);
  NVIC_EnableIRQ(GPIO_EVEN_IRQn);
  //
  //

  //
  //Setup timer 1 on PC1 for sensor trigger signal
  //Enable clock for TIMER1 module
  CMU_ClockEnable(cmuClock_TIMER1, true);
  //Set CC1 location pin 1 (PC1) as output
  GPIO_PinModeSet(TRIG_PORT, TRIG_PIN, gpioModeWiredAndPullUp, 0);
  //Set overflow value
  TIMER_TopSet(TIMER1, CMU_ClockFreqGet(cmuClock_HFPER)/TRIGGER_CALL_FREQ);
  //Construct time initialization structure
  TIMER_Init_TypeDef timerInit1 =
  {		.enable = true,
		  .debugRun = true,
		  .prescale = timerPrescale16,
		  .clkSel = timerClkSelHFPerClk,
		  .fallAction = timerInputActionNone,
		  .riseAction = timerInputActionNone,
		  .mode = timerModeUp,
		  .dmaClrAct = false,
		  .quadModeX4 = false,
		  .oneShot = false,
		  .sync = false,
  };
  //Enable overflow interrupt
  TIMER_IntEnable(TIMER1, TIMER_IF_OF);
  //Enable TIMER1 interrupt vector in NVIC
  NVIC_EnableIRQ(TIMER1_IRQn);
  //Configure timer
  TIMER_Init(TIMER1, &timerInit1);
  //
  //

  //
  //Setup timer 0 on PD7 for sensor trigger signal
  //Enable clock for TIMER0 module
  CMU_ClockEnable(cmuClock_TIMER0, true);
  //Set CC1 location pin 7 (PD7) as output
  GPIO_PinModeSet(PWM_PORT, PWM_PIN, gpioModeWiredAndPullUp, 0);
  //Set overflow value
  TIMER_TopSet(TIMER0, CMU_ClockFreqGet(cmuClock_HFPER)/PWM_FREQ/1.6);
  //Construct time initialization structure
  TIMER_Init_TypeDef timerInit0 =
  {		.enable = true,
		  .debugRun = true,
		  .prescale = timerPrescale16,
		  .clkSel = timerClkSelHFPerClk,
		  .fallAction = timerInputActionNone,
		  .riseAction = timerInputActionNone,
		  .mode = timerModeUp,
		  .dmaClrAct = false,
		  .quadModeX4 = false,
		  .oneShot = false,
		  .sync = false,
  };
  //Enable overflow interrupt
  TIMER_IntEnable(TIMER0, TIMER_IF_OF);
  //Enable TIMER1 interrupt vector in NVIC
  NVIC_EnableIRQ(TIMER0_IRQn);
  //Configure timer
  TIMER_Init(TIMER0, &timerInit0);
  //
  //

  INT_Enable();

  //Check if charging on startup, ISR won't catch charging on startup
  if (GPIO_PinInGet(CHARGE_PORT, CHARGE_PIN) == 1	) {
	  Charging = 1;
  }

  /* Infinite loop */
  while (1) {

  }
}
